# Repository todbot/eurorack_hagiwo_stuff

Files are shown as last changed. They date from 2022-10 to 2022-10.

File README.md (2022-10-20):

# eurorack_hagiwo_stuff

So far just a PCB version of ["additive_vco"](https://note.com/solder_state/n/n30b3a8737b1e)

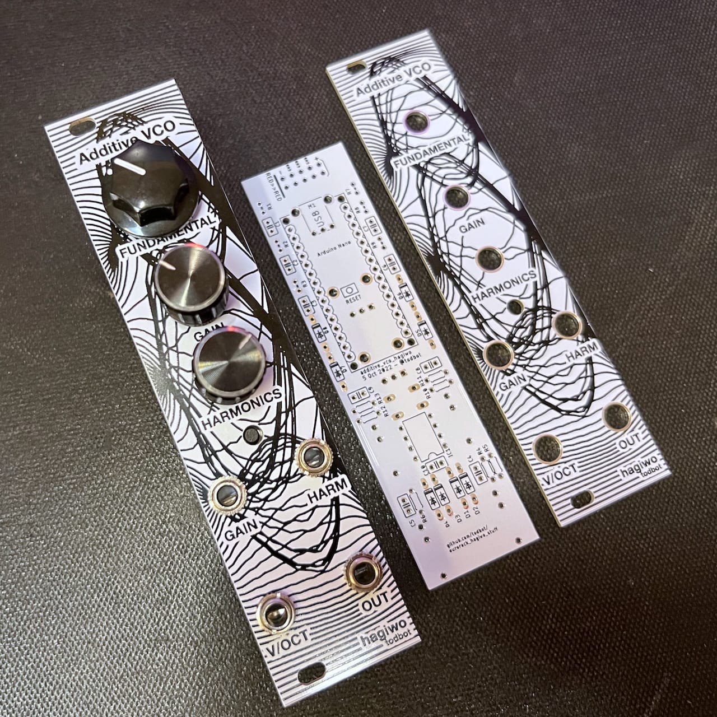
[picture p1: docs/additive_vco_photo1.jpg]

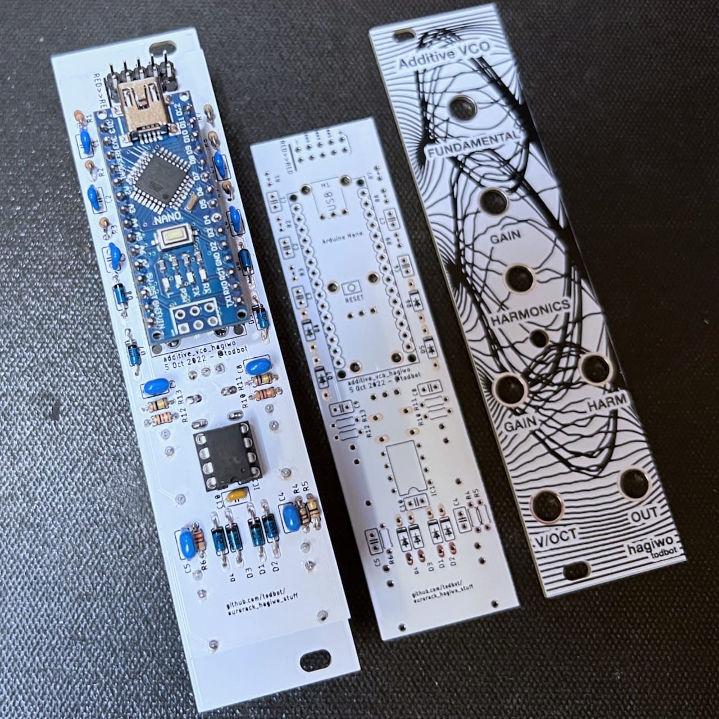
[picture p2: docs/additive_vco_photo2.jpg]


Here's a little demo video of it in action:

https://user-images.githubusercontent.com/274093/197078909-dfc56eac-acbd-4a94-ae75-ff46f5945844.mp4

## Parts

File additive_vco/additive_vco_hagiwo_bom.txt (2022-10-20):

Partlist exported from /Users/tod/projects/synth/eurorack_hagiwo_stuff/additive_vco/additive_vco_hagiwo.sch at 10/19/22 3:58 P

Qty Value                    Device                   Package            Parts                          Description
1                            10-XX                    B3F-10XX           S1                             OMRON SWITCH
8                            SCHOTTKY-DIODEDO35-7     DO35-7             D1, D2, D3, D4, D5, D6, D7, D8 Schottky Diode
1   100                      R-EU_0204/5              0204/5             R4                             RESISTOR, European symbol
3   100k                     9MM_SNAP-IN_POT_         9MM_SNAP-IN_POT    VR1, VR2, VR3                  9mm vertical snap-in pot, Alpha / Panasonic style
3   100k                     R-EU_0204/5              0204/5             R5, R11, R13                   RESISTOR, European symbol
1   100n                     C-EU025-025X050          C025-025X050       C10                            CAPACITOR, European symbol
5   10n                      C-EU025-025X050          C025-025X050       C1, C2, C3, C6, C7             CAPACITOR, European symbol
6   1k                       R-EU_0204/2V             0204V              R1, R2, R3, R9, R10, R12       RESISTOR, European symbol
1   220                      R-EU_0204/5              0204/5             R6                             RESISTOR, European symbol
1   3.9k                     R-EU_0204/2V             0204V              R8                             RESISTOR, European symbol
1   47uF                     C-EU025-025X050          C025-025X050       C5                             CAPACITOR, European symbol
1   499k                     R-EU_0204/2V             0204V              R7                             RESISTOR, European symbol
3   68nF                     C-EU025-025X050          C025-025X050       C4, C8, C9                     CAPACITOR, European symbol
1   ARDUINO-NANO-3.0         ARDUINO-NANO-3.0         ARDUINO-NANO-3.0   M1                             Arduino Nano 3.0 and compatible devices
1   EURO_POWER_HEADERREGULAR EURO_POWER_HEADERREGULAR EURO_POWER_HEADER  SV1                            Power Header
1   MCP6232                  MCP602P                  DIL08              IC1                            Single Op Amp 2.7V to 6.0V Single Supply CMOS
4   THONKICONNNEW            THONKICONNNEW            WQP-PJ301M-12_JACK J1, J2, J3, J4                 3.5mm socket for Eurorack modular synths

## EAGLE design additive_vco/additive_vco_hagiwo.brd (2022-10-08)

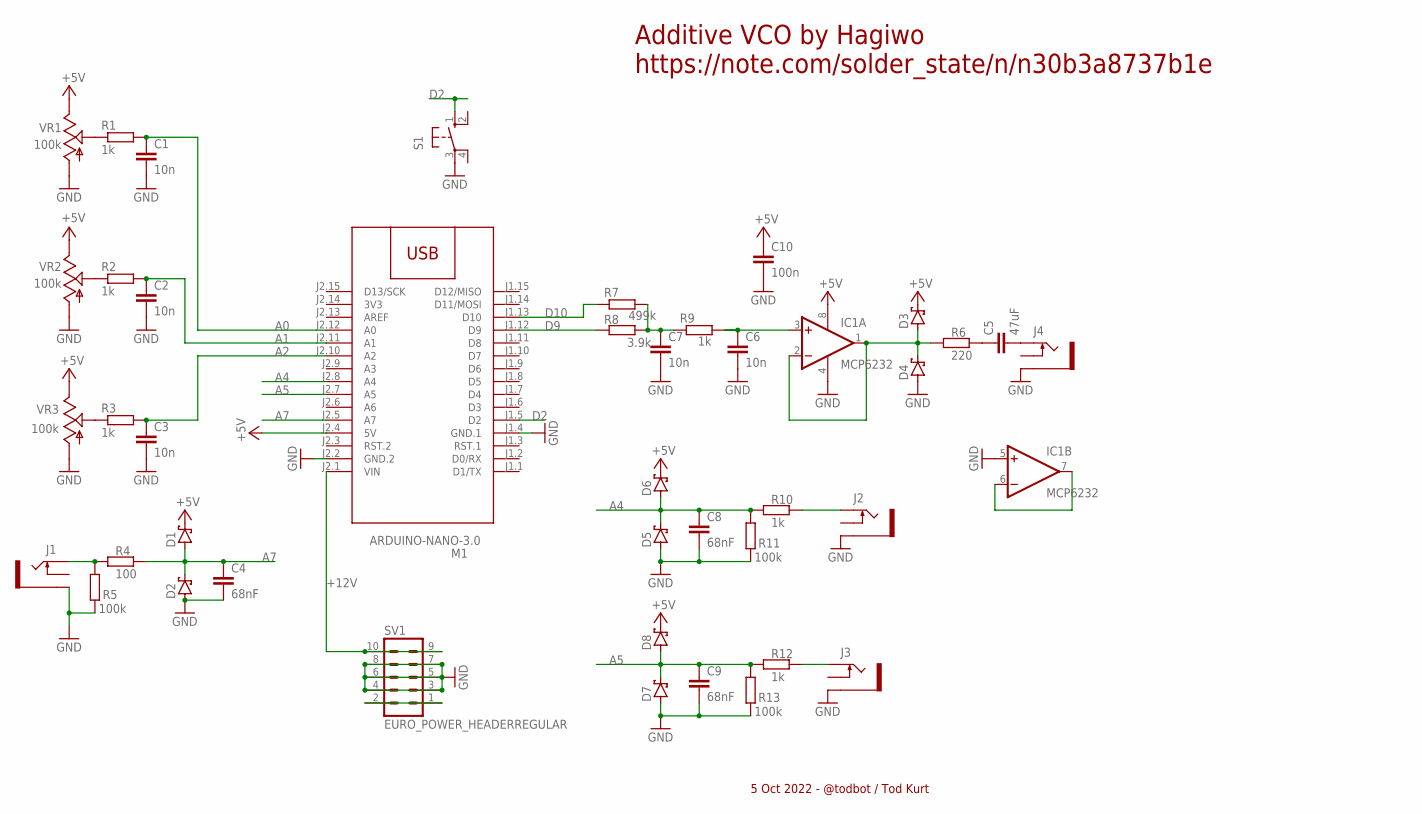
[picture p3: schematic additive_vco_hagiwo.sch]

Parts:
C1, C2, C3, C6, C7: 10n; C025-025X050
C4, C8, C9: 68nF; C025-025X050
C5: 47uF; C025-025X050
C10: 100n; C025-025X050
D1, D2, D3, D4, D5, D6, D7, D8: SCHOTTKY-DIODEDO35-7; DO35-7
IC1: MCP6232; DIL08
J1, J2, J3, J4: THONKICONNNEW; WQP-PJ301M-12_JACK
M1: ARDUINO-NANO-3.0
R1, R2, R3, R9: 1k; 0204V
R4: 100; 0204/5
R5, R11, R13: 100k; 0204/5
R6: 220; 0204/5
R7: 499k; 0204V
R8: 3.9k; 0204V
R10, R12: 1k; 0204/5
S1: 10-XX; B3F-10XX
SV1: EURO_POWER_HEADERREGULAR; EURO_POWER_HEADER
VR1, VR2, VR3: 100k; 9MM_SNAP-IN_POT

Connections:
3V3: M1.J2.14 (3V3)
+5V: C10.1, D1.C, D3.C, D6.C, D8.C, IC1.8 (V+), M1.J2.4 (5V), VR1.3 (E), VR2.3 (E), VR3.3 (E)
+12V: M1.J2.1 (VIN), SV1.9, SV1.10
A0: C1.1, M1.J2.12 (A0), R1.2
A1: C2.1, M1.J2.11 (A1), R2.2
A2: C3.1, M1.J2.10 (A2), R3.2
A4: C8.1, D5.C, D6.A, M1.J2.8 (A4), R10.1, R11.2
A5: C9.1, D7.C, D8.A, M1.J2.7 (A5), R12.1, R13.2
A7: C4.1, D1.A, D2.C, M1.J2.5 (A7), R4.2
D2: M1.J1.5 (D2), S1.1 (S)
D9: M1.J1.12 (D9), R8.1
D10: M1.J1.13 (D10), R7.1
GND: C1.2, C2.2, C3.2, C4.2, C6.2, C7.2, C8.2, C9.2, C10.2, D2.A, D4.A, D5.A, D7.A, IC1.4 (V-), IC1.5 (+IN), J1.P$3_SLEEVE (SLEEVE), J2.P$3_SLEEVE (SLEEVE), J3.P$3_SLEEVE (SLEEVE), J4.P$3_SLEEVE (SLEEVE), M1.J1.4 (GND.1), M1.J2.2 (GND.2), R5.1, R11.1, R13.1, S1.3, SV1.3, SV1.4, SV1.5, SV1.6, SV1.7, SV1.8, VR1.1 (A), VR2.1 (A), VR3.1 (A)
unnamed: R1.1, VR1.2 (S)
unnamed: R2.1, VR2.2 (S)
unnamed: R3.1, VR3.2 (S)
unnamed: C5.1, R6.2
unnamed: C5.2, J4.P$1_TIP (TIP)
unnamed: D3.A, D4.C, IC1.1 (OUT), IC1.2 (-IN), R6.1
unnamed: J1.P$1_TIP (TIP), R4.1, R5.2
unnamed: C6.1, IC1.3 (+IN), R9.2
unnamed: C7.1, R7.2, R8.2, R9.1
unnamed: SV1.1, SV1.2
unnamed: J2.P$1_TIP (TIP), R10.2
unnamed: IC1.6 (-IN), IC1.7 (OUT)
unnamed: J3.P$1_TIP (TIP), R12.2

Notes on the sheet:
Additive VCO by Hagiwo https://note.com/solder_state/n/n30b3a8737b1e
5 Oct 2022 - @todbot / Tod Kurt

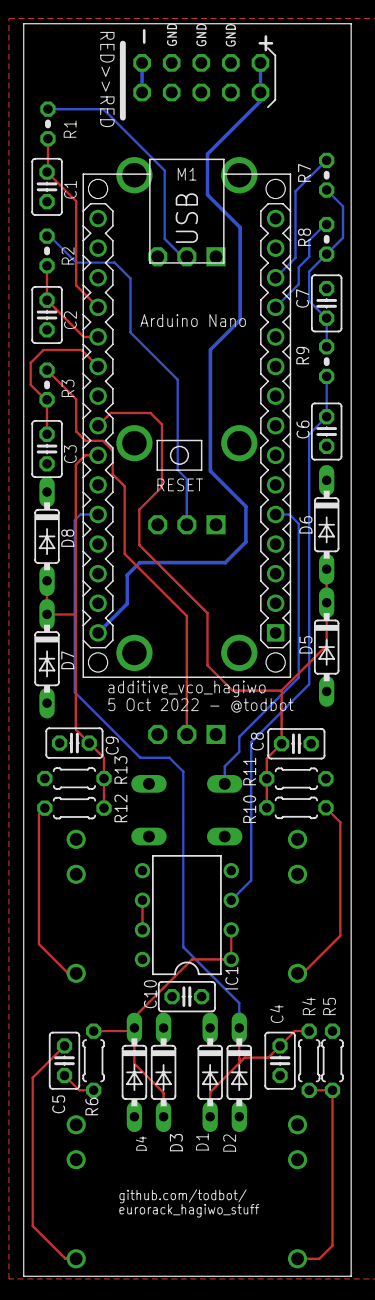
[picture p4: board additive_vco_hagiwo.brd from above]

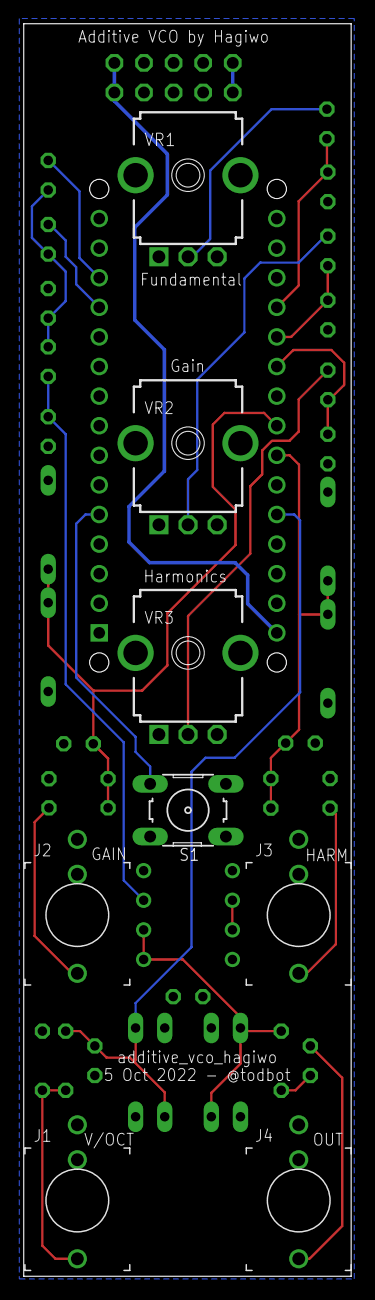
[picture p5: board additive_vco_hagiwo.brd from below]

Board: 2 copper layers, 28.1 x 107.5 mm, 42 parts (8 on the bottom side), 25 nets.

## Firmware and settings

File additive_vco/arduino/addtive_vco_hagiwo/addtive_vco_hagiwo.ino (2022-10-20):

// additive_vco by hagiwo
// Originally from: https://note.com/solder_state/n/n30b3a8737b1e
// Mods on 17 Oct 2022 by @todbot / Tod Kurt
// - Change harm_knob A3 -> A2 to match schematic
// - Remove two osillators (aSin7, aSin8) since was running out of CPU (Mozzi or Arduino core update?)
// To program:
// - Set Board to: Tools / Boards / Arduino AVR Boards / Arduino Nano
// - On some Nano boards, select Tools / Processor / ATmega328P (Old Bootloader)
// 
//
#include <MozziGuts.h>
#include <Oscil.h> // oscillator template
#include <tables/sin2048_int8.h> // sine table for oscillator

Oscil <SIN2048_NUM_CELLS, AUDIO_RATE> aSin1(SIN2048_DATA);
Oscil <SIN2048_NUM_CELLS, AUDIO_RATE> aSin2(SIN2048_DATA);
Oscil <SIN2048_NUM_CELLS, AUDIO_RATE> aSin3(SIN2048_DATA);
Oscil <SIN2048_NUM_CELLS, AUDIO_RATE> aSin4(SIN2048_DATA);
Oscil <SIN2048_NUM_CELLS, AUDIO_RATE> aSin5(SIN2048_DATA);
Oscil <SIN2048_NUM_CELLS, AUDIO_RATE> aSin6(SIN2048_DATA);
//Oscil <SIN2048_NUM_CELLS, AUDIO_RATE> aSin7(SIN2048_DATA);
//Oscil <SIN2048_NUM_CELLS, AUDIO_RATE> aSin8(SIN2048_DATA);

#define CONTROL_RATE 128 // Hz, powers of 2 are most reliable

int freq1 = 110;//base freq of OSC1
int voct = 1000;//external V/OCT LSB
int freqv1 = 440;// freq1 apply voct
int harm_knob = 0;//AD wave knob
byte gain = 127;

const static float voctpow[1024] PROGMEM = {
  0,  0.004882, 0.009765, 0.014648, 0.019531, 0.024414, 0.029296, 0.034179, 0.039062, 0.043945, 0.048828, 0.05371,  0.058593, 0.063476, 0.068359, 0.073242, 0.078125, 0.083007, 0.08789,  0.092773, 0.097656, 0.102539, 0.107421, 0.112304, 0.117187, 0.12207,  0.126953, 0.131835, 0.136718, 0.141601, 0.146484, 0.151367, 0.15625,  0.161132, 0.166015, 0.170898, 0.175781, 0.180664, 0.185546, 0.190429, 0.195312, 0.200195, 0.205078, 0.20996,  0.214843, 0.219726, 0.224609, 0.229492, 0.234375, 0.239257, 0.24414,  0.249023, 0.253906, 0.258789, 0.263671, 0.268554, 0.273437, 0.27832,  0.283203, 0.288085, 0.292968, 0.297851, 0.302734, 0.307617, 0.3125, 0.317382, 0.322265, 0.327148, 0.332031, 0.336914, 0.341796, 0.346679, 0.351562, 0.356445, 0.361328, 0.36621,  0.371093, 0.375976, 0.380859, 0.385742, 0.390625, 0.395507, 0.40039,  0.405273, 0.410156, 0.415039, 0.419921, 0.424804, 0.429687, 0.43457,  0.439453, 0.444335, 0.449218, 0.454101, 0.458984, 0.463867, 0.46875,  0.473632, 0.478515, 0.483398, 0.488281, 0.493164, 0.498046, 0.502929, 0.507812, 0.512695, 0.517578, 0.52246,  0.527343, 0.532226, 0.537109, 0.541992, 0.546875, 0.551757, 0.55664,  0.561523, 0.566406, 0.571289, 0.576171, 0.581054, 0.585937, 0.59082,  0.595703, 0.600585, 0.605468, 0.610351, 0.615234, 0.620117, 0.625,  0.629882, 0.634765, 0.639648, 0.644531, 0.649414, 0.654296, 0.659179, 0.664062, 0.668945, 0.673828, 0.67871,  0.683593, 0.688476, 0.693359, 0.698242, 0.703125, 0.708007, 0.71289,  0.717773, 0.722656, 0.727539, 0.732421, 0.737304, 0.742187, 0.74707,  0.751953, 0.756835, 0.761718, 0.766601, 0.771484, 0.776367, 0.78125,  0.786132, 0.791015, 0.795898, 0.800781, 0.805664, 0.810546, 0.815429, 0.820312, 0.825195, 0.830078, 0.83496,  0.839843, 0.844726, 0.849609, 0.854492, 0.859375, 0.864257, 0.86914,  0.874023, 0.878906, 0.883789, 0.888671, 0.893554, 0.898437, 0.90332,  0.908203, 0.913085, 0.917968, 0.922851, 0.927734, 0.932617, 0.9375, 0.942382, 0.947265, 0.952148, 0.957031, 0.961914, 0.966796, 0.971679, 0.976562, 0.981445, 0.986328, 0.99121,  0.996093, 1.000976, 1.005859, 1.010742, 1.015625, 1.020507, 1.02539,  1.030273, 1.035156, 1.040039, 1.044921, 1.049804, 1.054687, 1.05957,  1.064453, 1.069335, 1.074218, 1.079101, 1.083984, 1.088867, 1.09375,  1.098632, 1.103515, 1.108398, 1.113281, 1.118164, 1.123046, 1.127929, 1.132812, 1.137695, 1.142578, 1.14746,  1.152343, 1.157226, 1.162109, 1.166992, 1.171875, 1.176757, 1.18164,  1.186523, 1.191406, 1.196289, 1.201171, 1.206054, 1.210937, 1.21582,  1.220703, 1.225585, 1.230468, 1.235351, 1.240234, 1.245117, 1.25, 1.254882, 1.259765, 1.264648, 1.269531, 1.274414, 1.279296, 1.284179, 1.289062, 1.293945, 1.298828, 1.30371,  1.308593, 1.313476, 1.318359, 1.323242, 1.328125, 1.333007, 1.33789,  1.342773, 1.347656, 1.352539, 1.357421, 1.362304, 1.367187, 1.37207,  1.376953, 1.381835, 1.386718, 1.391601, 1.396484, 1.401367, 1.40625,  1.411132, 1.416015, 1.420898, 1.425781, 1.430664, 1.435546, 1.440429, 1.445312, 1.450195, 1.455078, 1.45996,  1.464843, 1.469726, 1.474609, 1.479492, 1.484375, 1.489257, 1.49414,  1.499023, 1.503906, 1.508789, 1.513671, 1.518554, 1.523437, 1.52832,  1.533203, 1.538085, 1.542968, 1.547851, 1.552734, 1.557617, 1.5625, 1.567382, 1.572265, 1.577148, 1.582031, 1.586914, 1.591796, 1.596679, 1.601562, 1.606445, 1.611328, 1.61621,  1.621093, 1.625976, 1.630859, 1.635742, 1.640625, 1.645507, 1.65039,  1.655273, 1.660156, 1.665039, 1.669921, 1.674804, 1.679687, 1.68457,  1.689453, 1.694335, 1.699218, 1.704101, 1.708984, 1.713867, 1.71875,  1.723632, 1.728515, 1.733398, 1.738281, 1.743164, 1.748046, 1.752929, 1.757812, 1.762695, 1.767578, 1.77246,  1.777343, 1.782226, 1.787109, 1.791992, 1.796875, 1.801757, 1.80664,  1.811523, 1.816406, 1.821289, 1.826171, 1.831054, 1.835937, 1.84082,  1.845703, 1.850585, 1.855468, 1.860351, 1.865234, 1.870117, 1.875,  1.879882, 1.884765, 1.889648, 1.894531, 1.899414, 1.904296, 1.909179, 1.914062, 1.918945, 1.923828, 1.92871,  1.933593, 1.938476, 1.943359, 1.948242, 1.953125, 1.958007, 1.96289,  1.967773, 1.972656, 1.977539, 1.982421, 1.987304, 1.992187, 1.99707,  2.001953, 2.006835, 2.011718, 2.016601, 2.021484, 2.026367, 2.03125,  2.036132, 2.041015, 2.045898, 2.050781, 2.055664, 2.060546, 2.065429, 2.070312, 2.075195, 2.080078, 2.08496,  2.089843, 2.094726, 2.099609, 2.104492, 2.109375, 2.114257, 2.11914,  2.124023, 2.128906, 2.133789, 2.138671, 2.143554, 2.148437, 2.15332,  2.158203, 2.163085, 2.167968, 2.172851, 2.177734, 2.182617, 2.1875, 2.192382, 2.197265, 2.202148, 2.207031, 2.211914, 2.216796, 2.221679, 2.226562, 2.231445, 2.236328, 2.24121,  2.246093, 2.250976, 2.255859, 2.260742, 2.265625, 2.270507, 2.27539,  2.280273, 2.285156, 2.290039, 2.294921, 2.299804, 2.304687, 2.30957,  2.314453, 2.319335, 2.324218, 2.329101, 2.333984, 2.338867, 2.34375,  2.348632, 2.353515, 2.358398, 2.363281, 2.368164, 2.373046, 2.377929, 2.382812, 2.387695, 2.392578, 2.39746,  2.402343, 2.407226, 2.412109, 2.416992, 2.421875, 2.426757, 2.43164,  2.436523, 2.441406, 2.446289, 2.451171, 2.456054, 2.460937, 2.46582,  2.470703, 2.475585, 2.480468, 2.485351, 2.490234, 2.495117, 2.5,  2.504882, 2.509765, 2.514648, 2.519531, 2.524414, 2.529296, 2.534179, 2.539062, 2.543945, 2.548828, 2.55371,  2.558593, 2.563476, 2.568359, 2.573242, 2.578125, 2.583007, 2.58789,  2.592773, 2.597656, 2.602539, 2.607421, 2.612304, 2.617187, 2.62207,  2.626953, 2.631835, 2.636718, 2.641601, 2.646484, 2.651367, 2.65625,  2.661132, 2.666015, 2.670898, 2.675781, 2.680664, 2.685546, 2.690429, 2.695312, 2.700195, 2.705078, 2.70996,  2.714843, 2.719726, 2.724609, 2.729492, 2.734375, 2.739257, 2.74414,  2.749023, 2.753906, 2.758789, 2.763671, 2.768554, 2.773437, 2.77832,  2.783203, 2.788085, 2.792968, 2.797851, 2.802734, 2.807617, 2.8125, 2.817382, 2.822265, 2.827148, 2.832031, 2.836914, 2.841796, 2.846679, 2.851562, 2.856445, 2.861328, 2.86621,  2.871093, 2.875976, 2.880859, 2.885742, 2.890625, 2.895507, 2.90039,  2.905273, 2.910156, 2.915039, 2.919921, 2.924804, 2.929687, 2.93457,  2.939453, 2.944335, 2.949218, 2.954101, 2.958984, 2.963867, 2.96875,  2.973632, 2.978515, 2.983398, 2.988281, 2.993164, 2.998046, 3.002929, 3.007812, 3.012695, 3.017578, 3.02246,  3.027343, 3.032226, 3.037109, 3.041992, 3.046875, 3.051757, 3.05664,  3.061523, 3.066406, 3.071289, 3.076171, 3.081054, 3.085937, 3.09082,  3.095703, 3.100585, 3.105468, 3.110351, 3.115234, 3.120117, 3.125,  3.129882, 3.134765, 3.139648, 3.144531, 3.149414, 3.154296, 3.159179, 3.164062, 3.168945, 3.173828, 3.17871,  3.183593, 3.188476, 3.193359, 3.198242, 3.203125, 3.208007, 3.21289,  3.217773, 3.222656, 3.227539, 3.232421, 3.237304, 3.242187, 3.24707,  3.251953, 3.256835, 3.261718, 3.266601, 3.271484, 3.276367, 3.28125,  3.286132, 3.291015, 3.295898, 3.300781, 3.305664, 3.310546, 3.315429, 3.320312, 3.325195, 3.330078, 3.33496,  3.339843, 3.344726, 3.349609, 3.354492, 3.359375, 3.364257, 3.36914,  3.374023, 3.378906, 3.383789, 3.388671, 3.393554, 3.398437, 3.40332,  3.408203, 3.413085, 3.417968, 3.422851, 3.427734, 3.432617, 3.4375, 3.442382, 3.447265, 3.452148, 3.457031, 3.461914, 3.466796, 3.471679, 3.476562, 3.481445, 3.486328, 3.49121,  3.496093, 3.500976, 3.505859, 3.510742, 3.515625, 3.520507, 3.52539,  3.530273, 3.535156, 3.540039, 3.544921, 3.549804, 3.554687, 3.55957,  3.564453, 3.569335, 3.574218, 3.579101, 3.583984, 3.588867, 3.59375,  3.598632, 3.603515, 3.608398, 3.613281, 3.618164, 3.623046, 3.627929, 3.632812, 3.637695, 3.642578, 3.64746,  3.652343, 3.657226, 3.662109, 3.666992, 3.671875, 3.676757, 3.68164,  3.686523, 3.691406, 3.696289, 3.701171, 3.706054, 3.710937, 3.71582,  3.720703, 3.725585, 3.730468, 3.735351, 3.740234, 3.745117, 3.75, 3.754882, 3.759765, 3.764648, 3.769531, 3.774414, 3.779296, 3.784179, 3.789062, 3.793945, 3.798828, 3.80371,  3.808593, 3.813476, 3.818359, 3.823242, 3.828125, 3.833007, 3.83789,  3.842773, 3.847656, 3.852539, 3.857421, 3.862304, 3.867187, 3.87207,  3.876953, 3.881835, 3.886718, 3.891601, 3.896484, 3.901367, 3.90625,  3.911132, 3.916015, 3.920898, 3.925781, 3.930664, 3.935546, 3.940429, 3.945312, 3.950195, 3.955078, 3.95996,  3.964843, 3.969726, 3.974609, 3.979492, 3.984375, 3.989257, 3.99414,  3.999023, 4.003906, 4.008789, 4.013671, 4.018554, 4.023437, 4.02832,  4.033203, 4.038085, 4.042968, 4.047851, 4.052734, 4.057617, 4.0625, 4.067382, 4.072265, 4.077148, 4.082031, 4.086914, 4.091796, 4.096679, 4.101562, 4.106445, 4.111328, 4.11621,  4.121093, 4.125976, 4.130859, 4.135742, 4.140625, 4.145507, 4.15039,  4.155273, 4.160156, 4.165039, 4.169921, 4.174804, 4.179687, 4.18457,  4.189453, 4.194335, 4.199218, 4.204101, 4.208984, 4.213867, 4.21875,  4.223632, 4.228515, 4.233398, 4.238281, 4.243164, 4.248046, 4.252929, 4.257812, 4.262695, 4.267578, 4.27246,  4.277343, 4.282226, 4.287109, 4.291992, 4.296875, 4.301757, 4.30664,  4.311523, 4.316406, 4.321289, 4.326171, 4.331054, 4.335937, 4.34082,  4.345703, 4.350585, 4.355468, 4.360351, 4.365234, 4.370117, 4.375,  4.379882, 4.384765, 4.389648, 4.394531, 4.399414, 4.404296, 4.409179, 4.414062, 4.418945, 4.423828, 4.42871,  4.433593, 4.438476, 4.443359, 4.448242, 4.453125, 4.458007, 4.46289,  4.467773, 4.472656, 4.477539, 4.482421, 4.487304, 4.492187, 4.49707,  4.501953, 4.506835, 4.511718, 4.516601, 4.521484, 4.526367, 4.53125,  4.536132, 4.541015, 4.545898, 4.550781, 4.555664, 4.560546, 4.565429, 4.570312, 4.575195, 4.580078, 4.58496,  4.589843, 4.594726, 4.599609, 4.604492, 4.609375, 4.614257, 4.61914,  4.624023, 4.628906, 4.633789, 4.638671, 4.643554, 4.648437, 4.65332,  4.658203, 4.663085, 4.667968, 4.672851, 4.677734, 4.682617, 4.6875, 4.692382, 4.697265, 4.702148, 4.707031, 4.711914, 4.716796, 4.721679, 4.726562, 4.731445, 4.736328, 4.74121,  4.746093, 4.750976, 4.755859, 4.760742, 4.765625, 4.770507, 4.77539,  4.780273, 4.785156, 4.790039, 4.794921, 4.799804, 4.804687, 4.80957,  4.814453, 4.819335, 4.824218, 4.829101, 4.833984, 4.838867, 4.84375,  4.848632, 4.853515, 4.858398, 4.863281, 4.868164, 4.873046, 4.877929, 4.882812, 4.887695, 4.892578, 4.89746,  4.902343, 4.907226, 4.912109, 4.916992, 4.921875, 4.926757, 4.93164,  4.936523, 4.941406, 4.946289, 4.951171, 4.956054, 4.960937, 4.96582,  4.970703, 4.975585, 4.980468, 4.985351, 4.990234, 4.995117
};
const static byte gain_table[8][256]PROGMEM = {
  {  255,  255,  254,  253,  251,  249,  247,  244,  242,  238,  235,  231,  227,  223,  218,  213,  208,  203,  197,  192,  186,  180,  173,  167,  161,  154,  148,  141,  134,  128,  121,  114,  108,  101,  94, 88, 82, 76, 70, 64, 58, 52, 47, 42, 37, 32, 28, 24, 20, 17, 14, 11, 8,  6,  4,  2,  1,  0,  0,  0,  0,  0,  1,  2,  4,  6,  8,  10, 13, 17, 20, 24, 28, 32, 37, 42, 47, 52, 58, 63, 69, 75, 81, 88, 94, 101,  107,  114,  120,  127,  134,  141,  147,  154,  160,  167,  173,  179,  185,  191,  197,  202,  208,  213,  218,  222,  227,  231,  235,  238,  241,  244,  247,  249,  251,  253,  254,  255,  255,  255,  255,  255,  254,  253,  251,  249,  247,  245,  242,  239,  235,  231,  227,  223,  218,  213,  208,  203,  198,  192,  186,  180,  174,  168,  161,  155,  148,  141,  135,  128,  121,  115,  108,  101,  95, 88, 82, 76, 70, 64, 58, 53, 47, 42, 37, 33, 28, 24, 20, 17, 14, 11, 8,  6,  4,  2,  1,  0,  0,  0,  0,  0,  1,  2,  4,  6,  8,  10, 13, 16, 20, 24, 28, 32, 37, 41, 46, 52, 57, 63, 69, 75, 81, 87, 94, 100,  107,  113,  120,  127,  133,  140,  147,  153,  160,  166,  173,  179,  185,  191,  197,  202,  207,  213,  217,  222,  226,  231,  234,  238,  241,  244,  247,  249,  251,  253,  254,  255,  255,  255,  255,  255,  254,  253,  251,  249,  247,  245,  242,  239,  235,  232,  228,  223,  219,  214 },
  { 221,  214,  207,  199,  191,  182,  173,  163,  153,  142,  132,  121,  111,  100,  90, 80, 70, 60, 51, 43, 35, 28, 22, 16, 11, 7,  4,  1,  0,  0,  0,  1,  4,  7,  11, 16, 21, 28, 35, 43, 51, 60, 69, 79, 89, 100,  110,  121,  131,  142,  152,  162,  172,  182,  191,  199,  207,  214,  221,  226,  231,  235,  238,  241,  242,  243,  242,  241,  239,  236,  231,  227,  221,  215,  207,  200,  191,  182,  173,  163,  153,  143,  132,  122,  111,  100,  90, 80, 70, 61, 52, 43, 35, 28, 22, 16, 11, 7,  4,  1,  0,  0,  0,  1,  3,  7,  11, 15, 21, 28, 35, 42, 51, 60, 69, 79, 89, 99, 110,  120,  131,  142,  152,  162,  172,  181,  190,  199,  207,  214,  220,  226,  231,  235,  238,  241,  242,  243,  242,  241,  239,  236,  232,  227,  221,  215,  208,  200,  192,  183,  173,  163,  153,  143,  133,  122,  111,  101,  90, 80, 71, 61, 52, 44, 36, 29, 22, 16, 11, 7,  4,  2,  0,  0,  0,  1,  3,  6,  10, 15, 21, 27, 34, 42, 51, 59, 69, 79, 89, 99, 109,  120,  131,  141,  152,  162,  171,  181,  190,  198,  206,  214,  220,  226,  231,  235,  238,  241,  242,  243,  242,  241,  239,  236,  232,  227,  221,  215,  208,  200,  192,  183,  174,  164,  154,  143,  133,  122,  112,  101,  91, 81, 71, 61, 52, 44, 36, 29, 22, 16, 11, 7,  4,  2,  0,  0,  0,  1,  3,  6,  10, 15, 21, 27, 34, 42  },
  { 165,  158,  150,  143,  135,  127,  119,  111,  103,  95, 87, 79, 72, 64, 57, 50, 44, 38, 32, 27, 22, 17, 13, 10, 7,  4,  2,  1,  0,  0,  0,  1,  2,  4,  6,  9,  13, 17, 21, 26, 32, 37, 44, 50, 57, 64, 71, 79, 87, 94, 102,  110,  118,  126,  134,  142,  150,  158,  165,  172,  179,  185,  192,  197,  203,  208,  212,  216,  220,  223,  225,  227,  229,  230,  230,  230,  229,  227,  226,  223,  220,  217,  213,  208,  203,  198,  192,  186,  179,  173,  166,  158,  151,  143,  135,  127,  119,  111,  103,  95, 87, 80, 72, 65, 58, 51, 44, 38, 32, 27, 22, 17, 13, 10, 7,  4,  2,  1,  0,  0,  0,  1,  2,  4,  6,  9,  13, 17, 21, 26, 31, 37, 43, 50, 57, 64, 71, 79, 86, 94, 102,  110,  118,  126,  134,  142,  150,  157,  165,  172,  179,  185,  191,  197,  203,  207,  212,  216,  220,  223,  225,  227,  229,  230,  230,  230,  229,  228,  226,  223,  220,  217,  213,  208,  203,  198,  192,  186,  180,  173,  166,  159,  151,  143,  136,  128,  120,  112,  103,  96, 88, 80, 72, 65, 58, 51, 44, 38, 32, 27, 22, 17, 13, 10, 7,  4,  2,  1,  0,  0,  0,  0,  2,  4,  6,  9,  13, 17, 21, 26, 31, 37, 43, 49, 56, 63, 71, 78, 86, 94, 102,  110,  118,  126,  134,  142,  149,  157,  164,  171,  178,  185,  191,  197,  202,  207,  212,  216,  219,  223,  225,  227,  229,  230,  230,  230 },
  { 97, 86, 75, 64, 54, 44, 36, 28, 20, 14, 9,  5,  2,  0,  0,  0,  2,  5,  9,  14, 20, 27, 35, 44, 54, 64, 74, 85, 97, 108,  119,  131,  142,  152,  162,  172,  181,  189,  196,  202,  208,  212,  215,  216,  217,  217,  215,  212,  208,  203,  197,  189,  181,  173,  163,  153,  142,  131,  120,  109,  97, 86, 75, 64, 54, 45, 36, 28, 21, 14, 9,  5,  2,  0,  0,  0,  2,  5,  9,  14, 20, 27, 35, 44, 53, 64, 74, 85, 96, 108,  119,  130,  141,  152,  162,  172,  181,  189,  196,  202,  207,  212,  215,  216,  217,  217,  215,  212,  208,  203,  197,  190,  182,  173,  163,  153,  143,  132,  120,  109,  98, 86, 75, 65, 55, 45, 36, 28, 21, 14, 9,  5,  2,  0,  0,  0,  2,  5,  9,  14, 20, 27, 35, 44, 53, 63, 74, 85, 96, 107,  119,  130,  141,  152,  162,  171,  180,  188,  196,  202,  207,  211,  215,  216,  217,  217,  215,  212,  208,  203,  197,  190,  182,  173,  164,  154,  143,  132,  121,  109,  98, 87, 76, 65, 55, 45, 36, 28, 21, 15, 9,  5,  2,  0,  0,  0,  2,  4,  8,  13, 20, 27, 35, 43, 53, 63, 73, 84, 96, 107,  118,  130,  141,  151,  162,  171,  180,  188,  196,  202,  207,  211,  214,  216,  217,  217,  215,  212,  208,  203,  197,  190,  182,  173,  164,  154,  143,  132,  121,  110,  98, 87, 76, 65, 55, 46, 37, 28, 21, 15, 10, 5,  2,  0,  0,  0 },
  { 46, 42, 38, 33, 30, 26, 22, 19, 16, 13, 11, 8,  6,  5,  3,  2,  1,  0,  0,  0,  0,  0,  1,  2,  3,  4,  6,  8,  11, 13, 16, 19, 22, 26, 29, 33, 37, 42, 46, 51, 55, 60, 65, 70, 75, 80, 86, 91, 96, 102,  107,  112,  118,  123,  128,  133,  138,  143,  148,  153,  157,  162,  166,  170,  174,  178,  181,  185,  188,  190,  193,  195,  197,  199,  201,  202,  203,  204,  204,  204,  204,  204,  203,  202,  201,  199,  198,  196,  193,  191,  188,  185,  182,  178,  175,  171,  167,  162,  158,  153,  149,  144,  139,  134,  129,  124,  118,  113,  108,  102,  97, 92, 86, 81, 76, 71, 66, 61, 56, 51, 46, 42, 38, 34, 30, 26, 23, 19, 16, 13, 11, 9,  6,  5,  3,  2,  1,  0,  0,  0,  0,  0,  1,  2,  3,  4,  6,  8,  10, 13, 16, 19, 22, 25, 29, 33, 37, 41, 46, 50, 55, 60, 65, 70, 75, 80, 85, 91, 96, 101,  107,  112,  117,  123,  128,  133,  138,  143,  148,  153,  157,  162,  166,  170,  174,  178,  181,  184,  187,  190,  193,  195,  197,  199,  201,  202,  203,  204,  204,  204,  204,  204,  203,  202,  201,  199,  198,  196,  193,  191,  188,  185,  182,  178,  175,  171,  167,  163,  158,  154,  149,  144,  139,  134,  129,  124,  119,  113,  108,  103,  97, 92, 87, 81, 76, 71, 66, 61, 56, 51, 47, 42, 38, 34, 30, 26, 23, 20, 16, 14, 11, 9,  7,  5,  3,  2 },
  { 9,  5,  3,  1,  0,  0,  0,  1,  3,  5,  8,  12, 17, 22, 27, 34, 40, 47, 55, 62, 70, 79, 87, 95, 104,  112,  120,  128,  136,  143,  150,  157,  163,  169,  174,  178,  182,  186,  188,  190,  191,  191,  191,  190,  188,  186,  183,  179,  174,  169,  164,  157,  151,  144,  136,  129,  121,  113,  104,  96, 88, 79, 71, 63, 55, 48, 41, 34, 28, 22, 17, 13, 9,  5,  3,  1,  0,  0,  0,  1,  3,  5,  8,  12, 17, 22, 27, 33, 40, 47, 54, 62, 70, 78, 87, 95, 103,  112,  120,  128,  136,  143,  150,  157,  163,  169,  174,  178,  182,  186,  188,  190,  191,  191,  191,  190,  188,  186,  183,  179,  175,  169,  164,  158,  151,  144,  137,  129,  121,  113,  105,  96, 88, 80, 71, 63, 56, 48, 41, 34, 28, 22, 17, 13, 9,  6,  3,  1,  0,  0,  0,  1,  3,  5,  8,  12, 16, 21, 27, 33, 40, 47, 54, 62, 70, 78, 86, 95, 103,  111,  120,  128,  135,  143,  150,  157,  163,  168,  174,  178,  182,  185,  188,  190,  191,  191,  191,  190,  188,  186,  183,  179,  175,  170,  164,  158,  151,  144,  137,  129,  121,  113,  105,  96, 88, 80, 72, 64, 56, 48, 41, 35, 28, 23, 17, 13, 9,  6,  3,  1,  0,  0,  0,  1,  2,  5,  8,  12, 16, 21, 27, 33, 40, 47, 54, 62, 70, 78, 86, 94, 103,  111,  119,  127,  135,  142,  150,  156,  163,  168,  173,  178,  182,  185,  188,  190 },
  { 0,  0,  1,  3,  5,  7,  10, 13, 17, 20, 25, 29, 34, 39, 44, 50, 55, 61, 67, 73, 80, 86, 92, 98, 104,  111,  117,  122,  128,  134,  139,  144,  149,  153,  158,  161,  165,  168,  171,  173,  175,  177,  178,  178,  179,  179,  178,  177,  175,  173,  171,  168,  165,  162,  158,  154,  149,  145,  139,  134,  129,  123,  117,  111,  105,  99, 93, 86, 80, 74, 68, 62, 56, 50, 45, 39, 34, 29, 25, 21, 17, 13, 10, 7,  5,  3,  2,  0,  0,  0,  0,  0,  1,  3,  5,  7,  10, 13, 16, 20, 24, 29, 34, 39, 44, 49, 55, 61, 67, 73, 79, 85, 92, 98, 104,  110,  116,  122,  128,  133,  139,  144,  149,  153,  157,  161,  165,  168,  171,  173,  175,  177,  178,  178,  179,  179,  178,  177,  175,  173,  171,  168,  165,  162,  158,  154,  150,  145,  140,  134,  129,  123,  117,  111,  105,  99, 93, 87, 80, 74, 68, 62, 56, 50, 45, 40, 34, 30, 25, 21, 17, 13, 10, 8,  5,  3,  2,  0,  0,  0,  0,  0,  1,  3,  5,  7,  10, 13, 16, 20, 24, 29, 33, 38, 44, 49, 55, 61, 67, 73, 79, 85, 91, 98, 104,  110,  116,  122,  128,  133,  139,  144,  148,  153,  157,  161,  165,  168,  171,  173,  175,  177,  178,  178,  179,  179,  178,  177,  175,  174,  171,  169,  166,  162,  158,  154,  150,  145,  140,  135,  129,  124,  118,  112,  106,  99, 93, 87, 81, 74, 68, 62, 56, 51, 45, 40  },
  { 15, 21, 27, 34, 41, 49, 57, 65, 74, 83, 91, 100,  108,  116,  124,  131,  138,  144,  150,  155,  159,  162,  164,  165,  166,  165,  164,  162,  159,  155,  150,  145,  139,  132,  125,  117,  109,  100,  92, 83, 74, 66, 57, 49, 41, 34, 27, 21, 16, 11, 7,  4,  1,  0,  0,  0,  1,  3,  7,  10, 15, 21, 27, 33, 41, 48, 57, 65, 74, 82, 91, 100,  108,  116,  124,  131,  138,  144,  150,  154,  158,  162,  164,  165,  166,  165,  164,  162,  159,  155,  150,  145,  139,  132,  125,  117,  109,  101,  92, 83, 75, 66, 58, 49, 42, 34, 27, 21, 16, 11, 7,  4,  1,  0,  0,  0,  1,  3,  6,  10, 15, 20, 27, 33, 40, 48, 56, 65, 73, 82, 91, 99, 108,  116,  124,  131,  138,  144,  150,  154,  158,  162,  164,  165,  166,  166,  164,  162,  159,  155,  150,  145,  139,  132,  125,  117,  109,  101,  92, 84, 75, 66, 58, 50, 42, 35, 28, 21, 16, 11, 7,  4,  2,  0,  0,  0,  1,  3,  6,  10, 15, 20, 26, 33, 40, 48, 56, 64, 73, 82, 90, 99, 107,  116,  123,  131,  138,  144,  149,  154,  158,  161,  164,  165,  166,  166,  164,  162,  159,  155,  151,  145,  139,  132,  125,  118,  109,  101,  93, 84, 75, 67, 58, 50, 42, 35, 28, 22, 16, 11, 7,  4,  2,  0,  0,  0,  1,  3,  6,  10, 15, 20, 26, 33, 40, 48, 56, 64, 73, 81, 90, 99, 107,  115,  123,  131 }
};
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
void loop() {
  audioHook(); // required here
}

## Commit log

2022-10-07 skooch layout a bit to USB and power work out
    [additive_vco_hagiwo.brd, additive_vco_hagiwo.sch]
2022-10-07 first cut at front panel
    [additive_vco_hagiwo.brd, additive_vco_hagiwo_panel.brd]
2022-10-07 better front panel
    [additive_vco_hagiwo_panel.brd]
2022-10-08 submit to pcb fab
    [additive_vco_hagiwo.brd, additive_vco_hagiwo.sch, additive_vco_hagiwo_panel.brd]
2022-10-17 fix too panel pot holes. wth tod?
    [additive_vco_hagiwo_panel.brd]
2022-10-20 arduino code verified works

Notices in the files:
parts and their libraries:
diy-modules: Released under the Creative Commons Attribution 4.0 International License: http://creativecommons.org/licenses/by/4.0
